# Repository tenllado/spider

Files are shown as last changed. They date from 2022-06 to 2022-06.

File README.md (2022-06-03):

# Spider board

A simple board for a digital electronics laboratory. It is ment to use with a
breadboard, the board is used to generate inputs for digital circuits and show
outputs of them lighting the leds.

The board contains:
- 8 switches for 8 digital inputs
- 8 leds for 8 digital outputs
- 1 push button to generate a clock signal

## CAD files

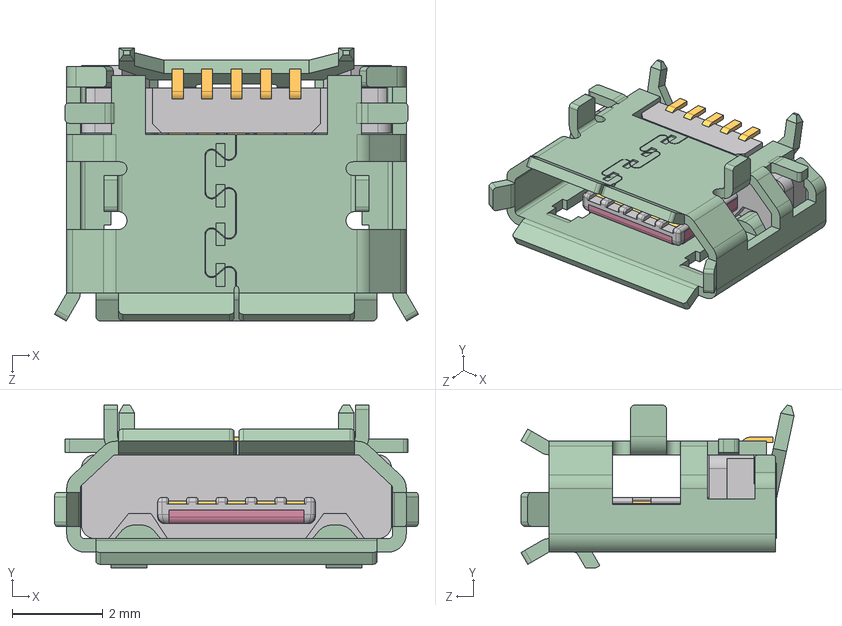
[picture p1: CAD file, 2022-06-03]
3dmodels/usb_b_micro.STEP
8.04 x 3.60 x 6.03 mm
MICRO-USB-SCOKET-HOUSING
MICRO-USB-SCOKET-INSERT-TML
SHIELD
SUS_PLATE

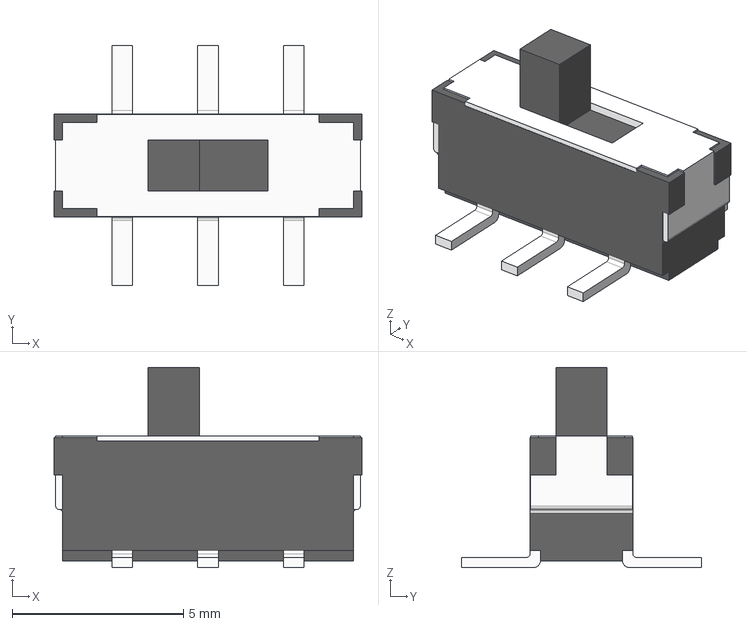
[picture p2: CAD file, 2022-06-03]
3dmodels/PZ_Switch_SMD.step
9.00 x 7.00 x 5.85 mm

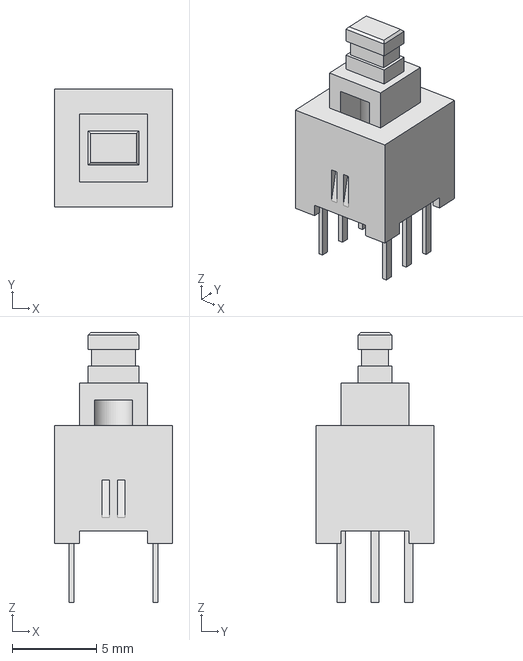
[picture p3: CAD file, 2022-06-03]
3dmodels/TL2230OAF140.STEP
7.00 x 7.00 x 16.0 mm

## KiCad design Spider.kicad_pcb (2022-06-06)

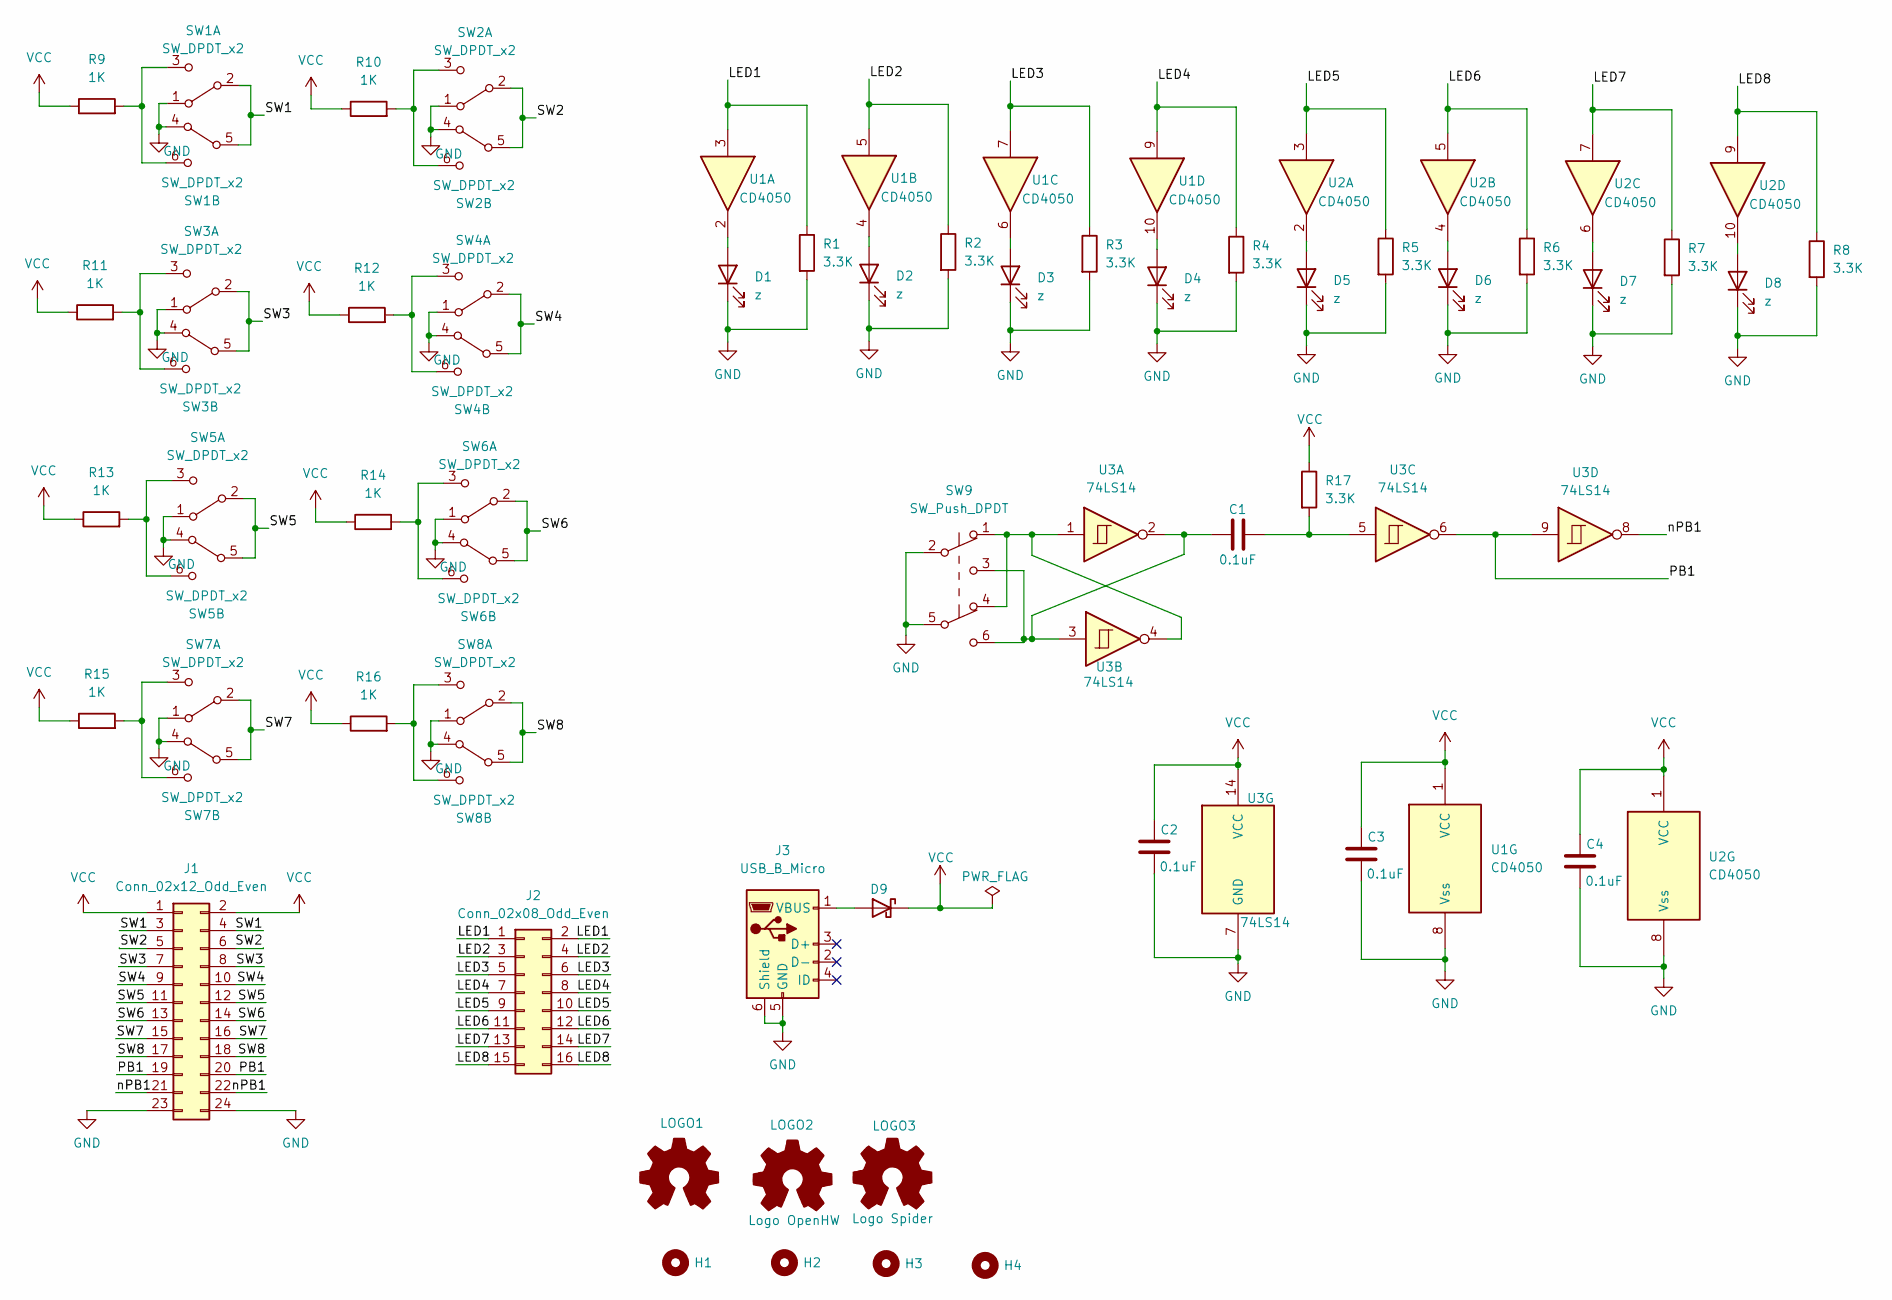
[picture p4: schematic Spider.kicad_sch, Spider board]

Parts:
C1, C2, C3, C4: 0.1uF; C_0603_1608Metric_Pad1.08x0.95mm_HandSolder; MPN C0603C104J4RACTU
D1, D2, D3, D4, D5, D6, D7, D8: z; LED_0603_1608Metric_Pad1.05x0.95mm_HandSolder; MPN LTST-C193KRKT-2A
D9: D_SMA; MPN B340AE-13
H1, H2, H3, H4: (no value)
J1: Conn_02x12_Odd_Even; PinHeader_2x12_P2.54mm_Vertical_SMD; MPN SSM-112-L-DV
J2: Conn_02x08_Odd_Even; PinHeader_2x08_P2.54mm_Vertical_SMD; MPN SSM-108-F-DV-K-TR
J3: USB_B_Micro; USB_Micro-B_Amphenol_10103594-0001LF_Horizontal; MPN 10103594-0001LF
LOGO1: (no value)
LOGO2: Logo OpenHW; OSHW-Logo_7.5x8mm_SilkScreen
LOGO3: Logo Spider; spider_logo
R1, R2, R3, R4, R5, R6, R7, R8, R17: 3.3K; R_0805_2012Metric_Pad1.20x1.40mm_HandSolder; MPN ERJ-PB6B3303V
R9, R10, R11, R12, R13, R14, R15, R16: 1K; R_0805_2012Metric_Pad1.20x1.40mm_HandSolder; MPN ERA-6AEB102V
SW1, SW2, SW3, SW4, SW5, SW6, SW7, SW8: SW_DPDT_x2; SW_DPDT; MPN JS202011SCQN
SW9: SW_Push_DPDT; TL2230OAF140; MPN TL2230OAF140
U1, U2: CD4050; SOIC-16W_7.5x10.3mm_P1.27mm; MPN CD4050BDW
U3: 74LS14; SSOP-14_5.3x6.2mm_P0.65mm; MPN SN74LS14DBR

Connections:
/LED1: J2.1, J2.2, R1.1, U1.3
/LED2: J2.3, J2.4, R2.1, U1.5
/LED3: J2.5, J2.6, R3.1, U1.7
/LED4: J2.7, J2.8, R4.1, U1.9
/LED5: J2.9, J2.10, R5.1, U2.3
/LED6: J2.11, J2.12, R6.1, U2.5
/LED7: J2.13, J2.14, R7.1, U2.7
/LED8: J2.15, J2.16, R8.1, U2.9
/PB1: J1.19, J1.20, U3.6, U3.9
/SW1: J1.3, J1.4, SW1.2 (B), SW1.5 (B)
/SW2: J1.5, J1.6, SW2.2 (B), SW2.5 (B)
/SW3: J1.7, J1.8, SW3.2 (B), SW3.5 (B)
/SW4: J1.9, J1.10, SW4.2 (B), SW4.5 (B)
/SW5: J1.11, J1.12, SW5.2 (B), SW5.5 (B)
/SW6: J1.13, J1.14, SW6.2 (B), SW6.5 (B)
/SW7: J1.15, J1.16, SW7.2 (B), SW7.5 (B)
/SW8: J1.17, J1.18, SW8.2 (B), SW8.5 (B)
/nPB1: J1.21, J1.22, U3.8
GND: C2.2, C3.2, C4.2, D1.1 (K), D2.1 (K), D3.1 (K), D4.1 (K), D5.1 (K), D6.1 (K), D7.1 (K), D8.1 (K), J1.23, J1.24, J3.5 (GND), J3.6 (Shield), R1.2, R2.2, R3.2, R4.2, R5.2, R6.2, R7.2, R8.2, SW1.1 (A), SW1.4 (A), SW2.1 (A), SW2.4 (A), SW3.1 (A), SW3.4 (A), SW4.1 (A), SW4.4 (A), SW5.1 (A), SW5.4 (A), SW6.1 (A), SW6.4 (A), SW7.1 (A), SW7.4 (A), SW8.1 (A), SW8.4 (A), SW9.2 (B), SW9.5 (B), U1.8 (Vss), U2.8 (Vss), U3.7 (GND)
unnamed: C1.1, SW9.3 (C), SW9.6 (C), U3.2, U3.3
unnamed: C1.2, R17.2, U3.5
unnamed: D1.2 (A), U1.2
unnamed: D2.2 (A), U1.4
unnamed: D3.2 (A), U1.6
unnamed: D4.2 (A), U1.10
unnamed: D5.2 (A), U2.2
unnamed: D6.2 (A), U2.4
unnamed: D7.2 (A), U2.6
unnamed: D8.2 (A), U2.10
unnamed: D9.2 (A), J3.1 (VBUS)
unnamed: R9.2, SW1.3 (C), SW1.6 (C)
unnamed: R10.2, SW2.3 (C), SW2.6 (C)
unnamed: R11.2, SW3.3 (C), SW3.6 (C)
unnamed: R12.2, SW4.3 (C), SW4.6 (C)
unnamed: R13.2, SW5.3 (C), SW5.6 (C)
unnamed: R14.2, SW6.3 (C), SW6.6 (C)
unnamed: R15.2, SW7.3 (C), SW7.6 (C)
unnamed: R16.2, SW8.3 (C), SW8.6 (C)
unnamed: SW9.1 (A), SW9.4 (A), U3.1, U3.4
VCC: C2.1, C3.1, C4.1, D9.1 (K), J1.1, J1.2, R9.1, R10.1, R11.1, R12.1, R13.1, R14.1, R15.1, R16.1, R17.1, U1.1 (VCC), U2.1 (VCC), U3.14 (VCC)

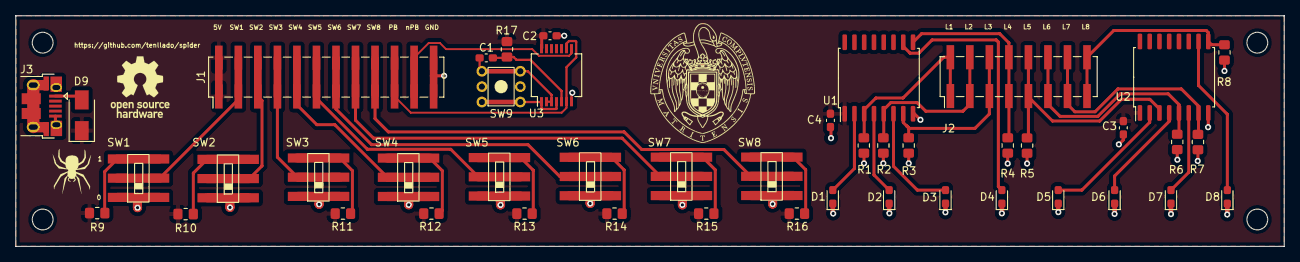
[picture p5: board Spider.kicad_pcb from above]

Board: 2 copper layers, 165.0 x 30.0 mm, 52 parts (0 on the bottom side), 40 nets.

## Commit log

2022-06-03 files for the project rev1.0
    [PZ_Switch_SMD.step, Spider.kicad_pcb, Spider.kicad_sch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]
2022-06-03 1-0 mark on silkscreen
    [Spider.kicad_pcb]
2022-06-03 url of project to silkscreen
    [Spider.kicad_pcb]
2022-06-06 split inputs and outputs, mounting holes, smd sockets
    [Spider.kicad_pcb, Spider.kicad_sch]
2022-06-06 remove small tracks, pcb erc warnings
    [Spider.kicad_pcb]
